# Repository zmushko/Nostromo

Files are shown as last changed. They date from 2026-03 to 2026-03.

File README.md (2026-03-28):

# NOSTROMO Terminal

A retro-futuristic Raspberry Pi 5 terminal inspired by the MU-TH-UR 6000 computer from Ridley Scott's *Alien* (1979). Features a CRT-style interface with AI conversation (Claude API), YouTube media playback, and hot-switchable screens — all running on a 3.5" display with a custom 3D-printed enclosure.

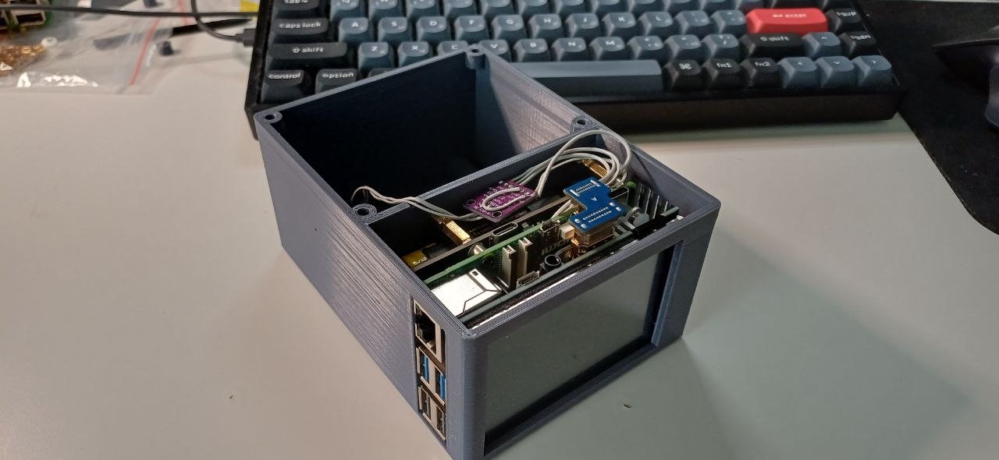
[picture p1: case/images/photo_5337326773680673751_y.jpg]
Nostromo Prototype v1


## Overview

Nostromo is a standalone terminal device built around Raspberry Pi 5 with a WaveShare 3.5" HDMI touchscreen. It combines a sci-fi aesthetic with practical functionality: AI assistant access, media playback, and an immersive boot sequence that recreates the MU-TH-UR 6000 experience.

The project includes both the software (Python/pygame) and the hardware design (OpenSCAD enclosure, I²S audio, 3D-printed case).

## Features

- **MU-TH-UR 6000 AI Terminal** — CRT-style green phosphor interface with Claude API backend, typewriter text effects, scanlines
- **Claude Terminal** — General-purpose AI assistant with the same retro aesthetic
- **YouTube Player** — Native video playback with ffpyplayer, OSD overlay, keyboard controls
- **Hot-switching** — Alt+1/2/3 switches between screens instantly; background audio continues
- **Boot sequence** — Authentic startup animation inspired by the Nostromo's onboard systems
- **I²S audio** — Digital audio path via MAX98357A amplifier, mono mix through ALSA
- **3D-printed enclosure** — Custom case designed in OpenSCAD, FDM optimized
- **Remote control app** — Android companion app (Flutter) for sharing YouTube links and controlling playback from your phone

## Hardware

### Bill of Materials

| Component | Specification | Notes |
|---|---|---|
| Raspberry Pi 5 | 4GB or 8GB | Main compute |
| WaveShare 3.5" HDMI LCD | 480×320, resistive touch | Sits on GPIO header |
| MAX98357A | I²S DAC + 3W amplifier | Digital audio, no analog noise |
| Speaker | 90×50mm oval, 8Ω, 6W | Side-firing orientation |
| UPS HAT | Dual 18650 | Optional, for portability |
| 3D-printed enclosure | PLA+, ~134×98×67mm | Two compartments: RPi + speaker |

### Wiring — I²S Audio

```
RPi5 GPIO              MAX98357A
─────────              ─────────
Pin 4  (5V)     ───→   VIN
Pin 6  (GND)    ───→   GND
Pin 12 (GPIO18) ───→   BCLK
Pin 35 (GPIO19) ───→   LRC
Pin 40 (GPIO21) ───→   DIN
                       GAIN  → floating (mono L+R mix)
                       SD    → VIN (enable)
```

### Enclosure

The case is designed in OpenSCAD with two internal compartments:

- **Left compartment** — Raspberry Pi 5 + UPS HAT stack
- **Right compartment** — Sealed speaker chamber with damping material

Speaker is side-firing for optimal speech clarity at desk distance.

## Software Architecture

```
main.py                          ← Entry point
├── nostromo/
│   ├── __init__.py              ← Package config, constants
│   ├── app.py                   ← NostromoApp base (pygame, CRT rendering)
│   ├── screen.py                ← Screen interface (activate/deactivate/is_alive)
│   └── manager.py               ← ScreenManager (main loop, hot-switching)
├── screens/
│   ├── ai_terminal.py           ← Shared AI terminal base (Claude API, typewriter)
│   ├── claude.py                ← Claude config + system prompt
│   ├── mother.py                ← MU-TH-UR 6000 config + system prompt
│   └── ytplay.py                ← MediaScreen (ffpyplayer, video + audio)
├── api/
│   └── server.py                ← HTTP API for mobile remote control
└── start.sh                     ← Startup script with auto-restart
```

### Key Design Decisions

- **Monolithic single-process** — All screens in one pygame process for instant switching
- **Lazy initialization** — Screens created on first activation
- **Background audio** — ytplay continues audio when switching screens; video decoding pauses
- **Shared AI base** — Claude and MU-TH-UR share `AITerminalScreen`, only config differs

## Audio Configuration

Pure digital audio path: RPi5 → I²S → MAX98357A → speaker.

### ALSA Mono Mix

```
# /etc/asound.conf
pcm.!default {
    type plug
    slave.pcm "mono"
}

pcm.mono {
    type route
    slave.pcm "plughw:0"
    ttable.0.0 1
    ttable.1.0 1
}
```

### Sound Card Ordering

```
# /etc/modprobe.d/alsa-base.conf
options snd_soc_rpi_simple_soundcard index=0
options vc4 index=1
```

### I²S Overlay

```
# /boot/firmware/config.txt
dtoverlay=hifiberry-dac
```

### Wi-Fi Power Management

Disable Wi-Fi power saving to prevent video buffering stutters:

```bash
sudo iw dev wlan0 set power_save off
sudo nmcli connection modify "<your-ssid>" wifi.powersave 2
```

The first command takes effect immediately, the second persists across reboots.

## Installation

### Prerequisites

- Raspberry Pi OS (Bookworm)
- Python 3.11+
- pygame, anthropic, ffpyplayer, yt-dlp

### Setup

```bash
git clone https://github.com/zmushko/Nostromo.git
cd Nostromo/software
pip install pygame anthropic ffpyplayer yt-dlp --break-system-packages
export ANTHROPIC_API_KEY="sk-ant-..."
python3 main.py --fullscreen
```

### Auto-start on boot

Nostromo starts automatically via autologin on tty1:

1. **Getty autologin** — `/etc/systemd/system/getty@tty1.service.d/override.conf`:
   ```ini
   [Service]
   ExecStart=
   ExecStart=-/sbin/agetty --autologin pi --noclear %I $TERM
   ```

2. **Bash profile** — `~/.bash_profile` launches `start.sh` only on tty1:
   ```bash
   if [ "$(tty)" = "/dev/tty1" ]; then
       exec ~/mother/start.sh
   fi
   ```

3. **`start.sh`** — sets up environment and auto-restarts on crash:
   ```bash
   export ANTHROPIC_API_KEY="your-key"
   export SDL_VIDEODRIVER=kmsdrm
   export SDL_AUDIODRIVER=alsa
   export AUDIODEV=plughw:2
   cd /home/pi/mother
   while true; do
       python3 main.py --fullscreen 2>> logs/nostromo.log
       sleep 3
   done
   ```

Crash logs are in `/home/pi/mother/logs/nostromo.log`.

Alternatively, a systemd service file (`mother.service`) is provided for `systemctl`-based setups.

## Printing the Enclosure

### Recommended Settings

| Parameter | Value |
|---|---|
| Material | eSUN PLA+ or PLA+HS |
| Nozzle temp | 215–220°C |
| Bed temp | 55–60°C |
| Layer height | 0.2mm |
| Infill | 20% |
| Speed | 50–80 mm/s |
| Retraction | 5mm (Bowden) |
| Brim | 5mm (for glass bed) |

### Assembly Hardware

- M2.5 heat-set inserts for RPi5 mounting
- M3 heat-set inserts (OD 3.77mm) for case assembly
- M2.5×6 screws

### Tolerances

+0.5mm clearance on all component pockets for FDM printing.
Print a test pocket before committing to the full case.

## Controls

| Key | Action |
|-----|---|
| Alt+1 | Switch to Claude terminal |
| Alt+2 | Switch to MU-TH-UR 6000 |
| Alt+3 | Switch to YouTube player |
| Enter | Send message / Confirm |
| Esc | Back / Exit current mode |
| ↑/↓ | Scroll history |

## Acknowledgments

This project was developed in collaboration with **Claude** (Anthropic), who served as co-designer for the software architecture, acoustic design, hardware selection, and enclosure engineering.

The MU-TH-UR 6000 interface and Nostromo name are references to the 1979 film *Alien*, directed by Ridley Scott. This is a fan project with no commercial affiliation.

## License

GPL-3.0

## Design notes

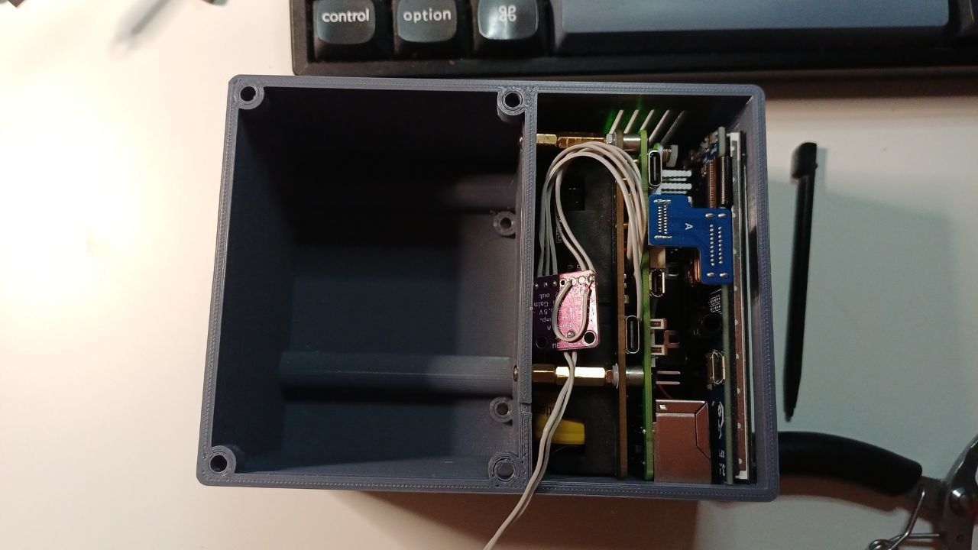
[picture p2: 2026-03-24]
case/images/photo_5334598438655564513_y.jpg

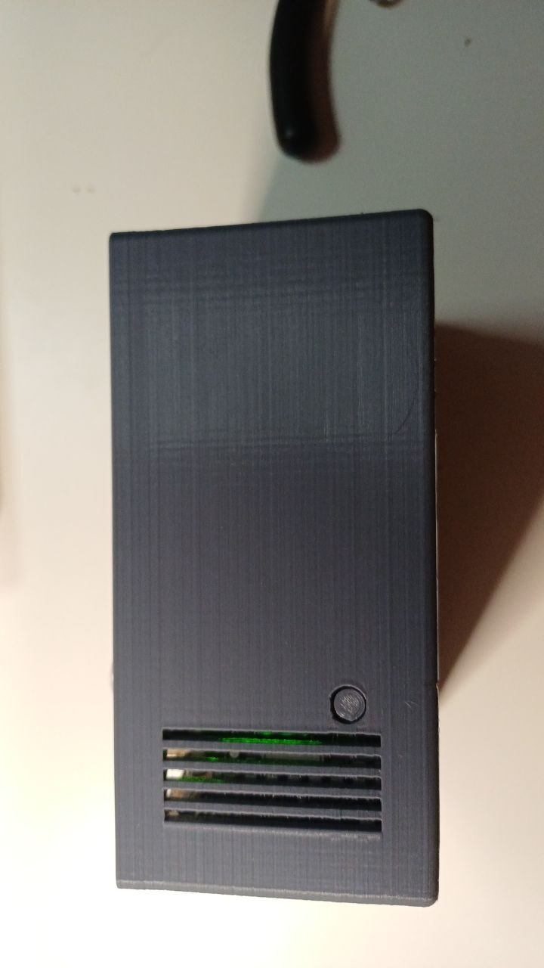
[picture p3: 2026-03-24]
case/images/photo_5334598438655564518_y.jpg

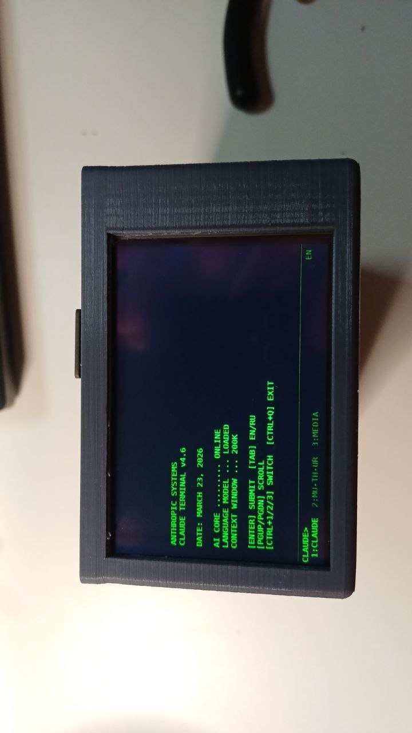
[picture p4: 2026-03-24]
case/images/photo_5334598438655564516_y.jpg

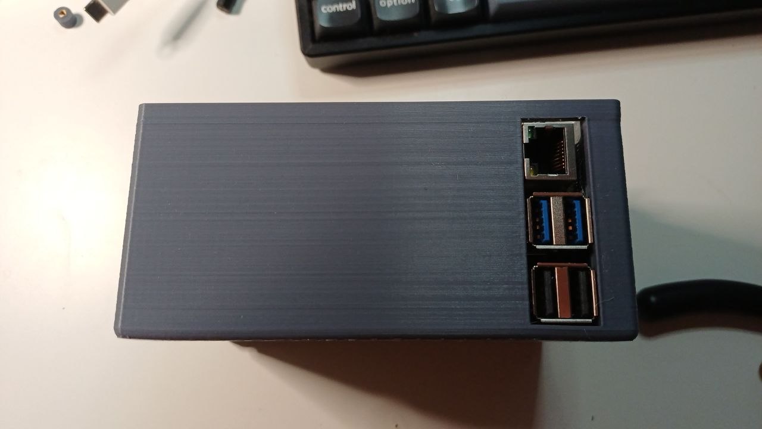
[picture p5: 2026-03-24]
case/images/photo_5334598438655564514_y.jpg

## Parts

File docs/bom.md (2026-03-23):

# Bill of Materials

## Electronics

| Component | Model | Qty | Notes |
|---|---|-----|---|
| Raspberry Pi 5 | 4GB/8GB | 1 | Main compute |
| WaveShare 3.5" HDMI LCD | 480×320 resistive | 1 | GPIO header mount |
| MAX98357A | I²S DAC+Amp 3W | 1 | Mono (GAIN floating) |
| Speaker | General Brands 90×50mm 8Ω 6W | 1 | Side-firing |
| UPS HAT | Dual 18650 | 1 | Optional |
| 18650 Batteries | Aspire 2600mAh | 2 | For UPS HAT |

## Fasteners

| Item | Size | Qty | Notes |
|---|---|-----|---|
| Heat-set inserts | M2.5 | 4 | RPi5 mounting |
| Heat-set inserts | M3 (OD 3.77mm) | 4 | Case assembly |
| Screws | M2.5×6 | 4 | RPi5 to bosses |
| Screws | M3×8 | 4 | Case assembly |

## 3D Printing

| Item | Notes |
|---|---|
| eSUN PLA+HS 1.75mm | Grey, 1kg spool |
| Pritt glue stick | For glass bed adhesion |

## Tools

| Tool | Model | Notes |
|---|---|---|
| Digital caliper | Dasqua 2000-2005 | ±0.02mm, DIN 862, IP54 |
| 3D Printer | Creality Ender 3 V2 Neo | Klipper firmware |
| Soldering iron | — | GPIO and heat-set inserts |
| Oscilloscope | — | I²S debugging |

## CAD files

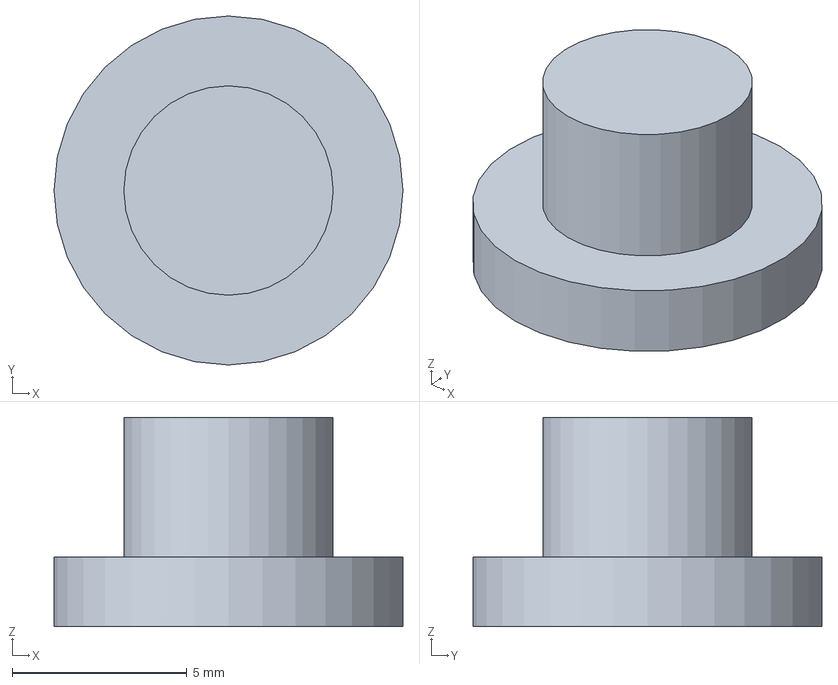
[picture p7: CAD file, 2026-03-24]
case/stl/pimpa.3mf
10.0 x 10.0 x 6.00 mm

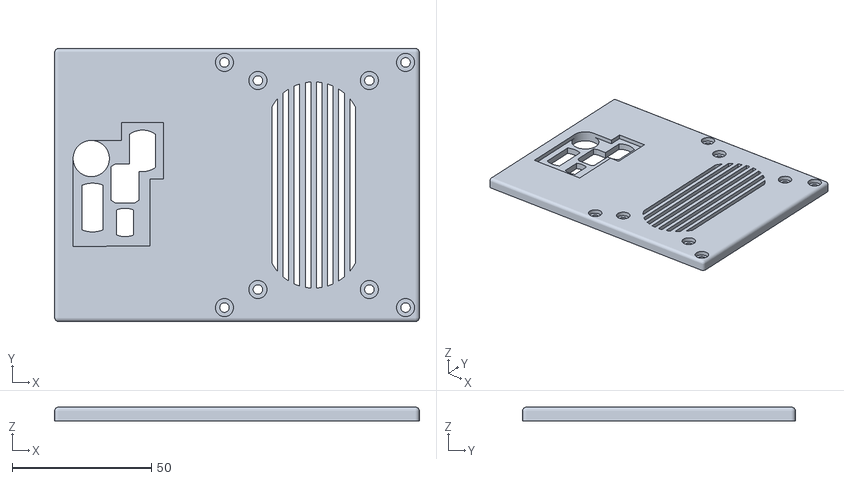
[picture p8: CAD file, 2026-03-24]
case/stl/cap.stl
131.0 x 98.0 x 4.99

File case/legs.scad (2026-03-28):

// Leg profile - Nostromo stand
module leg_profile() {
    polygon(points=[
        [0, 0],        // O - right angle
        [0, 31.94],    // A - top
        [9.23, 28.10], // B - 10mm along hypotenuse from A
        [20, 0]        // D - 20mm along base from O
    ]);
}

wall = 3;

module leg() {
    difference() {
        linear_extrude(height=15)
            leg_profile();

        translate([wall, wall, wall])
            cube([50, 50, 15 - 2*wall]);

        // M3 hole in the base (ZX plane)
        translate([10, -1, 15/2])
            rotate([-90, 0, 0])
                cylinder(h=wall+2, d=3.2, $fn=32);
    }
}

// First leg
leg();

// Second leg, offset 58mm along Z
translate([0, 0, 58])
    leg();

// Connecting bar along the base (XZ plane), trimmed to leg profile
intersection() {
    translate([0, 0, 15])
        cube([20, wall, 58 - 15]);
    linear_extrude(height=58 + 15)
        leg_profile();
}

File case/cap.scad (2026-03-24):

// ============================================
// NOSTROMO — Cap / Lid
// ============================================
// Sits on top of the case body (nostromo.scad)
// Print as-is (flat bottom on bed, rounded top up)
// No lip — held by M3 screws only
//
// Cap is 5mm thick for rigidity.
// Pockets (2mm deep from TOP) in port and screw areas
// bring local thickness down to 3mm.
// Speaker area: full 5mm (no pocket), grille cuts through.
// Speaker screw heads recessed into top surface.
// ============================================

// --- Import shared parameters from body ---
wall = 3;
$fn  = 32;

rpi_inner_x  = 92;
rpi_inner_y  = 52;
rpi_inner_z  = 61;

spk_inner_y  = 70;
spk_inner_x  = rpi_inner_x;
spk_inner_z  = rpi_inner_z;

outer_x = rpi_inner_y + wall + spk_inner_y + 2 * wall;
outer_y = rpi_inner_x + 2 * wall;
outer_z = rpi_inner_z + 2 * wall;

m3_boss_inner_d = 3.8;

// --- Cap parameters ---
cap_h     = 5;          // total cap thickness
thin_h    = 3;          // thickness in port/screw areas
pocket_d  = cap_h - thin_h;  // pocket depth = 2mm
pocket_z  = cap_h - pocket_d; // pocket starts at this Z (from top)
edge_r    = 1.5;        // rounding radius for top edges

// Screw holes — M3 through-holes (case bosses)
screw_d   = 3.4;
screw_pocket_d = 6.5;    // pocket diameter around each case screw

// Speaker screw head pocket
spk_screw_head_d = 6.5;    // M3 pan head diameter + clearance
spk_screw_head_h = 2;      // recess depth for screw head

// ============================================
// Speaker parameters (measured with Dasqua 2000-2005)
// ============================================
spk_body_x   = 50;     // speaker body width
spk_body_y   = 90;     // speaker body length
spk_mount_x  = 40;     // mounting holes spacing (width)
spk_mount_y  = 75;     // mounting holes spacing (length)
spk_mount_d  = 3.4;    // M3 through-holes for speaker

// Diaphragm (stadium/oblong shape)
spk_dia_w    = 40;     // diaphragm width
spk_dia_l    = 80;     // diaphragm length
spk_dia_r    = spk_dia_w / 2;  // corner radius = 20mm

// Speaker position — centered in speaker compartment
spk_chamber_x = wall + rpi_inner_y + wall;
spk_chamber_y = wall;
spk_center_x  = spk_chamber_x + spk_inner_y / 2;
spk_center_y  = spk_chamber_y + spk_inner_x / 2;

// Speaker grille
grille_slot_w    = 2;
grille_slot_gap  = 2;
grille_margin    = 3;       // inset from diaphragm edge

// ============================================
// USB-C cutout (X1200 UPS, faces up through cap)
// Measured with Dasqua 2000-2005
// ============================================
usbc_overmold_w  = 7.2;
usbc_overmold_l  = 12.2;
usbc_tol         = 1.0;
usbc_cut_w       = usbc_overmold_w + 2 * usbc_tol;  // 9.2mm
usbc_cut_l       = usbc_overmold_l + 2 * usbc_tol;  // 14.2mm
usbc_arc_r       = 8;
usbc_x           = 31.6;
usbc_y           = 61.25;
usbc_pocket_w    = usbc_cut_w + 6;
usbc_pocket_l    = usbc_cut_l + 6;

// ============================================
// Micro-HDMI cutouts (Pi5, 2x ports face up)
// Measured with Dasqua 2000-2005
// ============================================
hdmi_socket_w    = 7.1;
hdmi_socket_h    = 3.64;
hdmi_overmold_x  = 8;
hdmi_overmold_y  = 10;
hdmi_arc_r       = 8;

// HDMI 0 (no overmold)
hdmi0_cut_w      = 6;
hdmi0_cut_l      = 9;
hdmi0_x          = 23.5 + hdmi_socket_h / 2;  // 25.32
hdmi0_y          = 32 + hdmi_socket_w / 2;     // 35.55

// HDMI 1 (overmold passes through)
hdmi1_tol        = 1.0;
hdmi1_cut_w      = hdmi_overmold_x + 2 * hdmi1_tol;  // 10mm
hdmi1_cut_l      = hdmi_overmold_y + 2 * hdmi1_tol;  // 12mm
hdmi1_x          = 23.5 + hdmi_socket_h / 2;  // 25.32
hdmi1_y          = 46 + hdmi_socket_w / 2;     // 49.55

// Combined HDMI pocket
hdmi_pocket_margin = 4;

// ============================================
// Full-size HDMI cutout (WaveShare screen)
// ============================================
fhdmi_socket_w   = 15.12;
fhdmi_socket_h   = 5.6;
fhdmi_tol        = 1.0;
fhdmi_cut_w      = fhdmi_socket_h + 2 * fhdmi_tol;  // 7.6mm
fhdmi_cut_l      = 16;
fhdmi_arc_r      = 10;
fhdmi_x          = 10.88 + fhdmi_socket_h / 2;  // 13.68
fhdmi_y          = 33.35 + fhdmi_socket_w / 2;  // 40.91
fhdmi_pocket_w   = fhdmi_cut_w + 6;
fhdmi_pocket_l   = fhdmi_cut_l + 6;

// ============================================
// 3.5mm Audio jack cutout (round)
// ============================================
audio_d          = 5;    // 3.5mm jack diameter + clearance
audio_tol        = 1.0;
audio_cut_d      = audio_d + 2 * audio_tol;  // 7mm
audio_x          = 10.7 + audio_d / 2;   // 13.2
audio_y          = 56 + audio_d / 2;      // 58.5
audio_pocket_d   = audio_cut_d + 6;       // 13mm

// ============================================
// Case boss positions (must match body)
// ============================================
case_boss_positions = [
    [wall + 58,                                   wall + 2],
    [wall + 58,                                   wall + rpi_inner_x - 2],
    [wall + rpi_inner_y + spk_inner_y + wall - 2, wall + 2],
    [wall + rpi_inner_y + spk_inner_y + wall - 2, wall + rpi_inner_x - 2],
];

// ============================================
// MODULES
// ============================================

// Cap plate with rounded top edges, flat bottom
module cap_plate() {
    intersection() {
        translate([edge_r, edge_r, 0])
            minkowski() {
                cube([
                    outer_x - 2 * edge_r,
                    outer_y - 2 * edge_r,
                    cap_h - edge_r
                ]);
                sphere(r=edge_r, $fn=32);
            }

        translate([-1, -1, 0])
            cube([outer_x + 2, outer_y + 2, cap_h + 1]);
    }
}

// Stadium shape (2D) — rectangle with semicircle ends
module stadium_2d(w, l) {
    r = w / 2;
    straight = l - w;
    hull() {
        translate([0, -straight/2])
            circle(r=r, $fn=64);
        translate([0, straight/2])
            circle(r=r, $fn=64);
    }
}

// Barrel shape (2D) — straight long sides, arc short sides
module barrel_2d(w, l, arc_r) {
    half_w = w / 2;
    half_l = l / 2;
    arc_offset = sqrt(arc_r * arc_r - half_w * half_w);

    intersection() {
        translate([-half_w, -half_l - 1])
            square([w, l + 2]);

        translate([0, half_l - arc_offset])
            circle(r=arc_r, $fn=128);

        translate([0, -(half_l - arc_offset)])
            circle(r=arc_r, $fn=128);
    }
}

// ─── POCKETS (from TOP) ────────────────────────────────────
// NOTE: No speaker body pocket — full 5mm over speaker area

// Speaker screw head pockets (4 corners, from top)
module spk_screw_head_pockets() {
    for (dx = [-1, 1]) {
        for (dy = [-1, 1]) {
            translate([
                spk_center_x + dx * spk_mount_x / 2,
                spk_center_y + dy * spk_mount_y / 2,
                cap_h - spk_screw_head_h
            ])
                cylinder(d=spk_screw_head_d, h=spk_screw_head_h + 1, $fn=32);
        }
    }
}

// Combined pocket for both micro-HDMI ports
module hdmi_pocket() {
    min_x = hdmi0_x - hdmi1_cut_w / 2 - hdmi_pocket_margin;
    max_x = hdmi0_x + hdmi1_cut_w / 2 + hdmi_pocket_margin;
    min_y = hdmi0_y - hdmi0_cut_l / 2 - hdmi_pocket_margin;
    max_y = hdmi1_y + hdmi1_cut_l / 2 + hdmi_pocket_margin;
    translate([min_x, min_y, pocket_z])
        cube([max_x - min_x, max_y - min_y, pocket_d + 1]);
}

// USB-C pocket
module usbc_pocket() {
    translate([
        usbc_x - usbc_pocket_w / 2,
        usbc_y - usbc_pocket_l / 2,
        pocket_z
    ])
        cube([usbc_pocket_w, usbc_pocket_l, pocket_d + 1]);
}

// Full HDMI pocket
module fhdmi_pocket() {
    translate([
        fhdmi_x - fhdmi_pocket_w / 2,
        fhdmi_y - fhdmi_pocket_l / 2,
        pocket_z
    ])
        cube([fhdmi_pocket_w, fhdmi_pocket_l, pocket_d + 1]);
}

// Audio pocket
module audio_pocket() {
    translate([audio_x, audio_y, pocket_z])
        cylinder(d=audio_pocket_d, h=pocket_d + 1, $fn=64);
}

// Case screw pockets — circular around each case boss
module screw_pockets() {
    for (pos = case_boss_positions) {
        translate([pos[0], pos[1], pocket_z])
            cylinder(d=screw_pocket_d, h=pocket_d + 1, $fn=32);
    }
}

// ─── THROUGH-CUTS (full thickness) ─────────────────────────

// Speaker grille — slots clipped to diaphragm stadium shape
module speaker_grille() {
    dia_w = spk_dia_w - 2 * grille_margin;
    dia_l = spk_dia_l - 2 * grille_margin;

    slot_pitch = grille_slot_w + grille_slot_gap;
    n_slots = floor(dia_w / slot_pitch);
    pattern_w = n_slots * slot_pitch - grille_slot_gap;
    offset_x = -pattern_w / 2;

    translate([spk_center_x, spk_center_y, -0.5]) {
        linear_extrude(cap_h + 1) {
            intersection() {
                stadium_2d(dia_w, dia_l);
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

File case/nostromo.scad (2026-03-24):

// ============================================
// NOSTROMO — RPi5 Terminal + Speaker Case
// ============================================
// External: 126 x 94 x 65mm
// Left:  RPi5 compartment (53mm deep)
// Right: Speaker compartment (70mm deep)
// ============================================

// --- PARAMETERS --- undefined
wall = 3;       // wall thickness
$fn  = 32;       // number of facets for cylinders/spheres (higher = smoother, but slower render)

// Internal dimensions
rpi_inner_x  = 92;   // width (along front face)
rpi_inner_y  = 52;   // depth (front to back)
rpi_inner_z  = 61;   // height

spk_inner_y  = 70;   // speaker compartment depth
spk_inner_x  = rpi_inner_x;  // same width
spk_inner_z  = rpi_inner_z;  // same height

// Derived outer dimensions
outer_x = rpi_inner_y + wall + spk_inner_y + 2 * wall;  // 55+3+70+2*3 = 134mm
outer_y = rpi_inner_x + 2 * wall;                        // 92+6 = 98mm
outer_z = rpi_inner_z + 2 * wall;                        // 61+6 = 67mm

// Speaker diaphragm (oval)
spk_dia_x = 82;
spk_dia_z = 43;
spk_corner_r = spk_dia_z / 2;

// RPi5 mounting hole pattern in the center divider
rpi_mount_hole_d = 3.0;
rpi_mount_spacing_y = 58;
rpi_mount_spacing_z = 49;
rpi_board_size_y = 85.5;
rpi_board_size_z = 56.5;
rpi_mount_edge_offset_y = 3.5;
rpi_mount_edge_offset_z = 3.5;
rpi_ports_wall_clearance = 0;
rpi_floor_clearance = 0;
rpi_board_y = wall + rpi_inner_x - rpi_board_size_y - rpi_ports_wall_clearance;
rpi_board_z = wall + rpi_floor_clearance;

// inner diameter of bosses for M3 screws (for 2mm clearance on 2.5mm screws)
m3_boss_inner_d = 3.8;

// External screwdriver access arches for the lower RPi5 mounting holes
screwdriver_access_d = 6;
screwdriver_access_depth = wall + 2;

// Port cutout in the back wall of the RPi compartment
port_cutout_x = wall + 7;
port_cutout_z = wall + 1;
port_cutout_w = 17;
port_cutout_h = 54;
port_cutout_depth = outer_y - wall + 1;

// ============================================
// MODULES
// ============================================

module m3_boss(h=6) {
    difference() {
        cylinder(d=8, h=h, $fn=32);
        cylinder(d=m3_boss_inner_d, h=h+1, $fn=32);
    }
}

module rpi5_partition_mount_holes() {
    for (y_offset = [0, rpi_mount_spacing_y]) {
        for (z_offset = [0, rpi_mount_spacing_z]) {
                translate([
                    wall + rpi_inner_y - 1,
                    rpi_board_y + rpi_mount_edge_offset_y + y_offset,
                    rpi_board_z + rpi_mount_edge_offset_z + z_offset
                ])
                rotate([0, 90, 0])
                    cylinder(d=rpi_mount_hole_d, h=wall + 2, $fn=32);
        }
    }
}

module lower_rpi_screwdriver_access_arches() {
    for (y_pos = [
        rpi_board_y + rpi_mount_edge_offset_y,
        rpi_board_y + rpi_mount_edge_offset_y + rpi_mount_spacing_y
    ]) {
        translate([outer_x - wall - 1, y_pos - screwdriver_access_d / 2, 0])
            cube([screwdriver_access_depth, screwdriver_access_d, rpi_board_z + rpi_mount_edge_offset_z]);

        translate([outer_x - wall - 1, y_pos, rpi_board_z + rpi_mount_edge_offset_z])
            rotate([0, 90, 0])
                cylinder(d=screwdriver_access_d, h=screwdriver_access_depth, $fn=32);
    }
}

module screwdriver_access_arches() {
    for (y_pos = [
        rpi_board_y + rpi_mount_edge_offset_y - wall *2, 
        rpi_board_y + rpi_mount_edge_offset_y - wall + screwdriver_access_d,
        rpi_board_y + rpi_mount_edge_offset_y + rpi_mount_spacing_y - wall * 2,
        rpi_board_y + rpi_mount_edge_offset_y + rpi_mount_spacing_y - wall + screwdriver_access_d 
    ]) {
        translate([outer_x - wall - spk_inner_y, y_pos, wall])
            cube([spk_inner_y, wall, wall + 1]);

        // translate([outer_x - wall - 1, y_pos, rpi_board_z + rpi_mount_edge_offset_z])
        //     rotate([0, 90, 0])
        //         cylinder(d=screwdriver_access_d, h=screwdriver_access_depth, $fn=32);
    }
}

module make_arc(y) {
    difference() {
        translate([
            outer_x - wall - spk_inner_y, 
            y, 
            rpi_board_z + rpi_mount_edge_offset_z
        ])
            rotate([0, 90, 0])
                cylinder(d=12, h=spk_inner_y, $fn=32);
        
        translate([
            outer_x - wall - spk_inner_y, 
            y, 
            rpi_board_z + rpi_mount_edge_offset_z
        ])
            rotate([0, 90, 0])
                cylinder(d=screwdriver_access_d, h=spk_inner_y + wall + 1, $fn=32);
    
        translate([
            outer_x - wall - spk_inner_y, 
            y - screwdriver_access_d / 2, 
            0
        ])
            cube([spk_inner_y + wall + 1, screwdriver_access_d, rpi_board_z + rpi_mount_edge_offset_z]);
    }
}

// Main shell with two internal compartments
module nostromo() {
    difference() {
        // Outer shell (positioned so min coords = 0)
        // translate([0, 0, 0])
        //     cube([outer_x, outer_y, outer_z]);
        translate([wall, wall, wall])
            minkowski() {
                cube([outer_x - 2 * wall, outer_y - 2 * wall, outer_z - wall]);
                sphere(wall, $fn=32);
            }

        // RPi compartment (left side, open top)
        translate([wall, wall, wall])
            cube([rpi_inner_y, rpi_inner_x, rpi_inner_z + wall + 1]);

        // Speaker compartment (right side, open top)
        translate([wall + rpi_inner_y + wall, wall, wall])
            cube([spk_inner_y, spk_inner_x, spk_inner_z + wall + 1]);

        // mounting holes for RPi5 in the divider wall
        rpi5_partition_mount_holes();

        // external screwdriver access for the two lower RPi5 mounting holes
        lower_rpi_screwdriver_access_arches();

        // remove material for top cap
        translate([0, 0, outer_z - wall - 1])
            cube([outer_x, outer_y, 2 * wall + 1]);

        // remove material for screen (front face)
        translate([0, wall + 13, wall + 3])
            cube([wall + 1, 75, 51]);

        // remove material for ports
        translate([port_cutout_x, outer_y - wall - 1, port_cutout_z])
            cube([port_cutout_w, port_cutout_depth, port_cutout_h]);

            // color("red", 0.4)
        //remove material for corner
        // translate([0, 80, wall + 1])
        //     cube([16, 20, 54]);

        // cut top for test fitting (comment out before STL export)
        // translate([0, 0, wall + 6])
        //     cube([outer_x + 1, outer_y + 1, wall + 100]);

        // remove material for power button (round hole)
        translate([38.5, 0, wall + 14])
            rotate([-90, 0, 0])
                cylinder(d=7, h=8, $fn=32);

        // cat material for cooling vents (top face, left side)
        for (i = [0:4]) {
            translate([wall + 12 + i * 4, 0, wall + 8])
                cube([2, 4, 42]);
        }

        // cut material for scruwdriver access to lower RPi5 mounting holes (back face)
        translate([outer_x - wall - spk_inner_y, rpi_board_y + rpi_mount_edge_offset_y - wall, 0])
            cube([spk_inner_y + wall + 1, screwdriver_access_d, wall + 1]);

        translate([outer_x - wall - spk_inner_y, rpi_board_y + rpi_mount_edge_offset_y - wall + rpi_mount_spacing_y, 0])
            cube([spk_inner_y + wall + 1, screwdriver_access_d, wall + 1]);

        // cat small hole for the wired speaker
        translate([wall + 20, outer_y - 20, rpi_inner_z + wall - 2])
                cube([100, 2, 1]);

        translate([wall + 58, wall + 20, 0])
            cylinder(d=m3_boss_inner_d, h=wall + 1, $fn=32);
        translate([wall + 58, wall + rpi_inner_x - 14, 0])
            cylinder(d=m3_boss_inner_d, h=wall + 1, $fn=32);
        // cut for test fitting (comment out before STL export)
        // translate([62, 0, 0])
        //     cube([outer_x + 1, outer_y + 1, wall + 100]);
    }
}

// Ghost: RPi5 stack (for fit check)
// module ghost_rpi() {
//     color("green", 0.4)
//         translate([wall + (rpi_inner_y - 50) / 2,
//              rpi_board_y,
//              rpi_board_z])
//          cube([50, rpi_board_size_y, rpi_board_size_z]);
// }

// // Ghost: speaker (for fit check)
// module ghost_speaker() {
//     color("orange", 0.4)
//     translate([wall + rpi_inner_y + wall + (spk_inner_y - 30) / 2,
//                wall + (spk_inner_x - 82) / 2,
//                outer_z - 15])
//         cube([30, 82, 15]);
// }



// ============================================
// RENDER
// ============================================

nostromo();

// Ghost components (comment out before STL export)
// ghost_rpi();
// ghost_speaker();

        // M3 mounting bosses (4 per compartment)
// translate([wall + rpi_inner_y + wall + 2, wall + 2, wall + rpi_inner_z - 6])
//     m3_boss();
// translate([wall + rpi_inner_y + wall + 2, wall + rpi_inner_x -2,  wall + rpi_inner_z - 6])
//     m3_boss();
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

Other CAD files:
case/pimpa.scad
case/stl/pimpa.stl

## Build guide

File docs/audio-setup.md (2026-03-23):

# Audio Setup Guide

## Overview

Pure digital audio path — no external DAC needed:

```
RPi5 → I²S (digital) → MAX98357A (DAC + amp) → Speaker
```

## Step-by-Step Setup

### 1. Enable I²S Overlay

```bash
sudo nano /boot/firmware/config.txt
```

Add:
```
dtoverlay=hifiberry-dac
```

Reboot: `sudo reboot`

### 2. Verify Device

```bash
aplay -l
```

Look for `snd_rpi_hifiberry_dac` — should be card 0.

### 3. Test Sound

```bash
speaker-test -D plughw:0 -c 2 -t wav
```

### 4. Configure Mono Mix

```bash
sudo nano /etc/asound.conf
```

```
pcm.!default {
    type plug
    slave.pcm "mono"
}

pcm.mono {
    type route
    slave.pcm "plughw:0"
    ttable.0.0 1
    ttable.1.0 1
}
```

### 5. Fix Sound Card Ordering

```bash
sudo nano /etc/modprobe.d/alsa-base.conf
```

```
options snd_soc_rpi_simple_soundcard index=0
options vc4 index=1
```

### 6. Disable PipeWire (optional)

```bash
systemctl --user mask pipewire.socket pipewire-pulse.socket pipewire pipewire-pulse wireplumber
```

## Environment Variables (start.sh)

```bash
export SDL_AUDIODRIVER=alsa
export AUDIODEV=plughw:0
```

## Troubleshooting

| Problem | Cause | Solution |
|---|---|---|
| No sound | SD pin floating | Connect SD → VIN |
| No sound | Wrong card number | Check `aplay -l`, update asound.conf |
| No sound | PipeWire holding device | `systemctl --user stop pipewire*` |
| Only left channel | GAIN pulled to GND | Use ALSA mono mix (ttable) |
| ffpyplayer silent | Missing env var | `export AUDIODEV=plughw:0` |

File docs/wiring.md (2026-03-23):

# Wiring Guide

## I²S Audio (RPi5 → MAX98357A)

Solder to GPIO header **underside** (WaveShare uses top SPI pins, no conflict).

```
RPi5 GPIO              MAX98357A
─────────              ─────────
Pin 4  (5V)     ───→   VIN
Pin 6  (GND)    ───→   GND
Pin 12 (GPIO18) ───→   BCLK    ⚠️ Internal row, 6th from top!
Pin 35 (GPIO19) ───→   LRC
Pin 40 (GPIO21) ───→   DIN
```

### Pin Configuration

- **GAIN** → Leave floating. Mono mode: (L+R)/2 at 9dB gain.
- **SD** (Shutdown) → Connect to **VIN**. Enables the amplifier permanently.

### Common Mistakes

- Pin 12 is in the **internal** row — easy to miss by one pin
- Verify BCLK with oscilloscope: ~1.5MHz square wave during playback
- If no sound: check SD pin is connected to VIN
- If only left channel: GAIN may be pulled to GND on PCB despite labeling. Use ALSA mono mix.

## ALSA Configuration

See [audio-setup.md](audio-setup.md) for complete audio configuration guide.

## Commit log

2026-03-23 Initial project structure: README, docs, case, and configuration
    [nostromo.scad, printer-reference.cfg]
2026-03-23 Add prototype photo v1
2026-03-23 Add prototype photo to README
2026-03-23 Add Nostromo software
    Complete Python/pygame terminal framework:
    - Multi-screen manager with Ctrl+1/2/3 hot-switching
    - Claude AI terminal (Sonnet 4.6)
    - MU-TH-UR 6000 mainframe (in-character Alien RP)
    - YouTube media player with ffpyplayer
    - CRT effects: scanlines, vignette, phosphor glow
    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
2026-03-24 add new cap and nostromo stl
    [cap.scad, cap.stl, nostromo.scad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]
2026-03-25 Add Settings screen (Ctrl+4): system info, WiFi, Bluetooth
    New screen: screens/settings.py
    - System info: hostname, IP, CPU temp/freq, RAM, disk, uptime, voltage
    - WiFi: status, scan networks, connect/disconnect, enable/disable
    - Bluetooth: status, paired devices, scan, enable/disable
    - Interactive menus with numbered options
    - All operations run in worker threads (non-blocking UI)
    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
2026-03-25 Fix bluetoothctl hang: use pipe+DEVNULL+timeout for all BT commands
    - _run() now uses stdin=DEVNULL and start_new_session=True
    to prevent interactive commands from hanging
    - TimeoutExpired returns empty string instead of error
    - New _bt_cmd() helper: pipes commands to bluetoothctl
    non-interactively via echo
    - BT scan uses 'timeout 6' wrapper to guarantee termination
    - _run_worker() wrapped in try/except for safety
    - _get_bt_info() parses bluetoothctl output for connection
    status and battery level
2026-03-25 Add command history (Up/Down arrows) to all terminals
    - BaseTerminal: persistent command history with Up/Down navigation
    - History saved per-screen in history/*.hist (max 100 entries)
    - Stashes current input when browsing, restores on Down past end
    - Skip consecutive duplicates, reset on Escape
    - AI terminals (Claude/Mother): history_name from log_name
    - Media terminal: history_name='ytplay', Up/Down=volume during playback
    - Added history/ to .gitignore
2026-03-28 add legs
    [legs.scad]
2026-03-28 Fix remote playback crashes, auto-switch to media screen, docs
    - Fix segfault: disable video decoding by default, enable on screen activate
    (pygame is not thread-safe, concurrent SDL calls from decode + main thread)
    - Fix mixer crash: call sound.quit() before pygame.mixer.quit() to prevent
    play_tick() from hitting destroyed mixer; add sound.reinit() after stop
    - Auto-switch to media screen (Ctrl+3) when video arrives from phone
    - Force-init media screen at startup so API works from any tab
    - Suppress /status poll spam in API logs
    - Add try/except to all API control endpoints
    - Default volume 30% (was 100%)
    - Update start.sh to capture stdout+stderr
    - Update mother.service (main.py, audio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
2026-03-29 Add animated Claude crab screensaver from SVG source
    Pixel-accurate crab mascot with component animation: body bob,
    4-leg walking cycle, arm swing, eye blink. Based on clawd-crab-walking.svg.
    Set as default screensaver mode.
